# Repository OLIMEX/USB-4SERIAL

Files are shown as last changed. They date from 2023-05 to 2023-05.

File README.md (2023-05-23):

# USB-4SERIAL

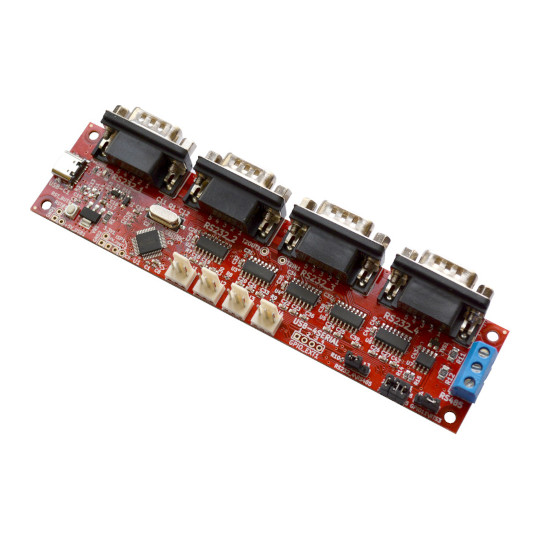
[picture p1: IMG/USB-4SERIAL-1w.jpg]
USB-4SERIAL-1w


USB-4SERIAL is Open Source Harrdware USB 2.0 High Speed to four RS232 levels or 3.3V TTL levels serial UARTs and one shared RS485 current loop serial port

## Features
* USB-C High Speed USB 2.0 connector for powering the board and communication
* The serial ports can be with baud rate up to 12Mbps on the TTL connector and up to 115200 bpx on RS232 levels connectors.
* The serial ports are compatible with 16C550 UART and support 5, 6, 7 or 8 data bits and 1 or 2 stop bits, odd, even, none, blank0, mark1 and other parity.
* Supports RTS and CTS hardware automatic flow control for the First one RS232 Serial port.
* Supports half-duplex and RS485 switching for the Fourth port.
* RS485 direction flow selectable by RTS3 or GPIO11
* Reset button
* High reliable industrial grade design -40+85C
* CE-RED and LVD certification
* Four mount holes 3 mm
* PCB dimensions: (150 x 35)mm ~ (5.9 x 1.38)"

Product page: https://www.olimex.com/Products/USB-Modules/USB-4SERIAL/open-source-hardware

## Licensee
* Hardware is released under CERN Open Hardware Licence Version 2 - Strongly Reciprocal, all silkscreen credits to Olimex should remain;
* Software is released under GPL3 Licensee
* Documentation is released under CC BY-SA 3.0

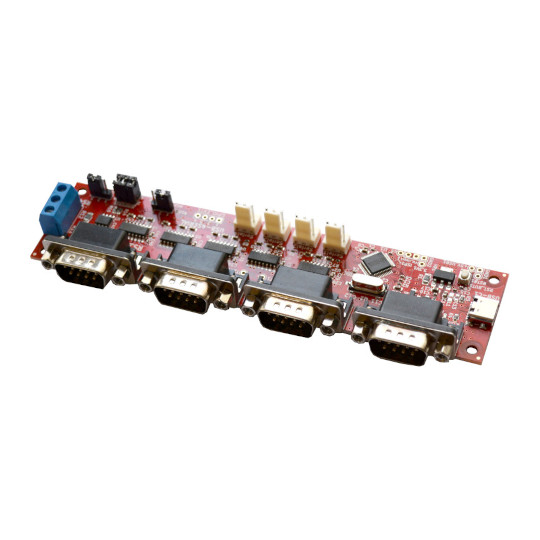
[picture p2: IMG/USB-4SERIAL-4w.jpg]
USB-4SERIAL-4w

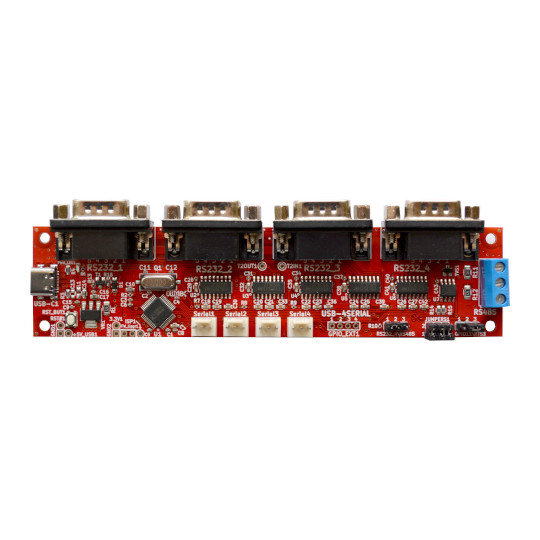
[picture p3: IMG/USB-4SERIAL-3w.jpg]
USB-4SERIAL-3w

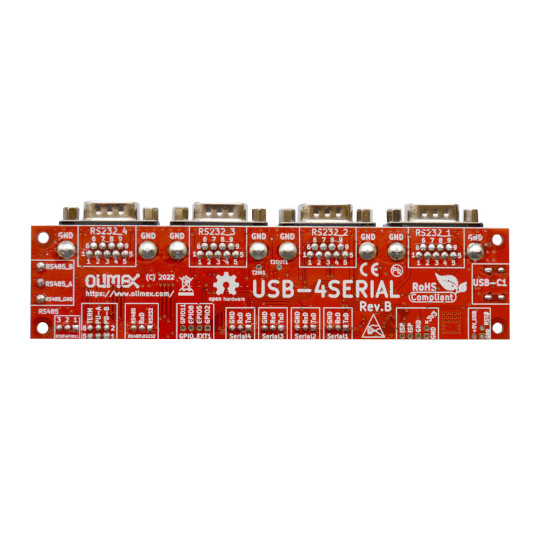
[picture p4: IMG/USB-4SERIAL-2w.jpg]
USB-4SERIAL-2w


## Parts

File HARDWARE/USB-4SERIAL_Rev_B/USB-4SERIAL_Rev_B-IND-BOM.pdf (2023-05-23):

# USB-4SERIAL_Rev_B-IND-BOM 10/04/2022

Quantity | Designation | Package | Designator
3 | 120R/R1206 | R_1206 | R1,R11,R12
5 | 330R/R0402 | R_0402 | R6,R7,R8,R9,R10
3 | 4.7k/R0603 | R_0603 | R14,R15,R16
2 | 5.1k/R0603 | R_0603 | R3,R4
2 | 12k/R0402 | R_0402 | R2,R13
1 | 20pF/50V/5%/C0G/C0603 | C_0603 | C10
2 | 39pF/50V/5%/C0G/C0402 | C_0402 | C11,C12
15 | 100nF/10V/10%/X7R/C0402 | C_0402 | C1,C2,C3,C4,C5,C6,C9, C15,C16,C28,C31,C34, C37,C40,C43
20 | 100nF/50V/20%/Y5V/C0603 | C_0603 | C18,C19,C20,C21,C22, C23,C24,C25,C26,C27, C29,C30,C32,C33,C35, C36,C38,C39,C41,C42
1 | 1uF/10V/10%/X5R/C0603 | C_0603 | C7
1 | 2.2uF/6.3V/20%/X5R/C0402 | C_0402 | C8
2 | 22uF/6.3V/20%/X5R/C0603 | C_0603 | C14,C17
1 | ESD5302F-3/TR(SOT-23-3) | SOT23-3 | TVS1
1 | 1N5819S4(SOD-123) | SOD-123 | D1
1 | LED/Red/0603 | LED_0603 | PWR_LED1
1 | LMUN2211LT1G(SOT-23) | SOT23 | T1
1 | AMS1117-3.3 (INDUSTRIAL) | SOT223 | VR1
1 | CH9344L(LQFP-48) | LQFP48 | U1
5 | ST3232BDR(SO-16) | SO-16 | U2,U3,U4,U5,U6
1 | YD3082EESA(SOIC-8_150mil) | SOIC-8_150mil | U7
1 | Q30MHz/20pF/30ppm/2P/ HC49-SM(SMD) | Q_49U3HMS | Q1
1 | YTS-A016-X | YTS-A016-X | RST_BUT1
4 | DB9_BMR(MALE) | DB9_BMR(MALE) | RS232_1,RS232_2, RS232_3,RS232_4
4 | MK-D-03-LF(WF3S) | MK-D-03-LF(WF3S)_ (CI3103P1V00) | Serial1,Serial2, Serial3,Serial4
1 | TB3-5MM (DG306-5.0-03P-12-00AH) | TB3-5mm | RS485
1 | USB-C-16P-F(A40-00119-A52-12) | USB2.0_TYPE-C (A40-00119-A52-12) | USB-C1
2 | HN1x3(1-2:Opened;2-3:Closed) | JP2 | RS232_4\RS485, GPIO11\RTS3
1 | HN2x3(Closed) | HN2x3 | JUMPERS1
1 | NA(FB0805/600R/2A) | L_0805 | L1
1 | NA(22uF/6.3V/20%/X5R/C0603) | C_0603 | C13
1 | NA(HN1x2) | HN1x2_Jumper | FW_Upgr1
1 | NA(HN1x4) | HN1x4 | GPIO_EXT1

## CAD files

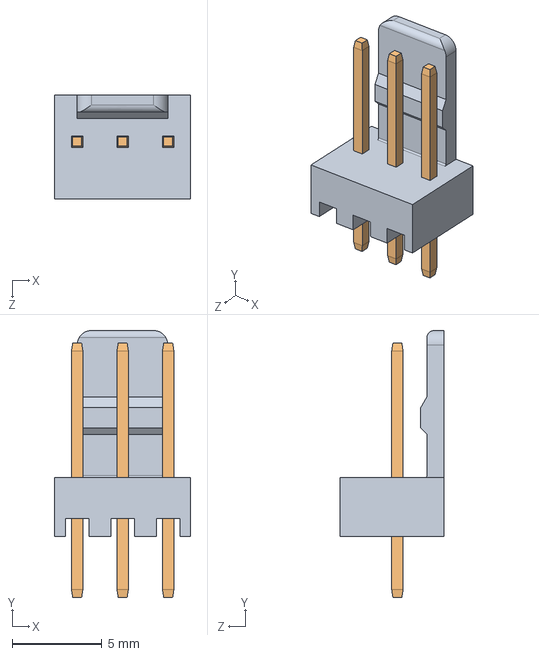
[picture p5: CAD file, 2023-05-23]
HARDWARE/USB-4SERIAL_Rev_B/3d/MK-D-03-LF(WF3S)_(CI3103P1V00_CVILUX).STEP
7.60 x 14.9 x 5.80 mm
CI31 3P
PIN V x 3

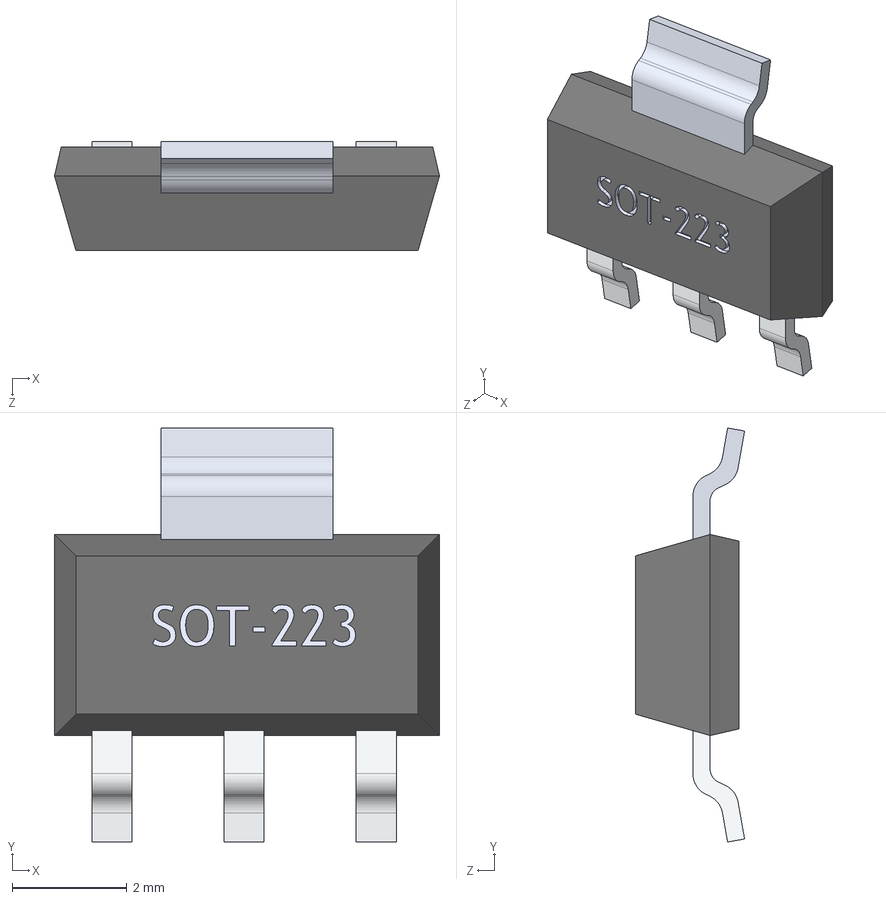
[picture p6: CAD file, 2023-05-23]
HARDWARE/USB-4SERIAL_Rev_B/3d/SOT-223-2.STEP
6.70 x 7.20 x 1.90 mm
User Library-SOT-223-2_PIN_SOT-223_2_1 x 3
User Library-SOT-223-2_SOT-223_1
User Library-SOT-223-2_PIN_SOT-223_1

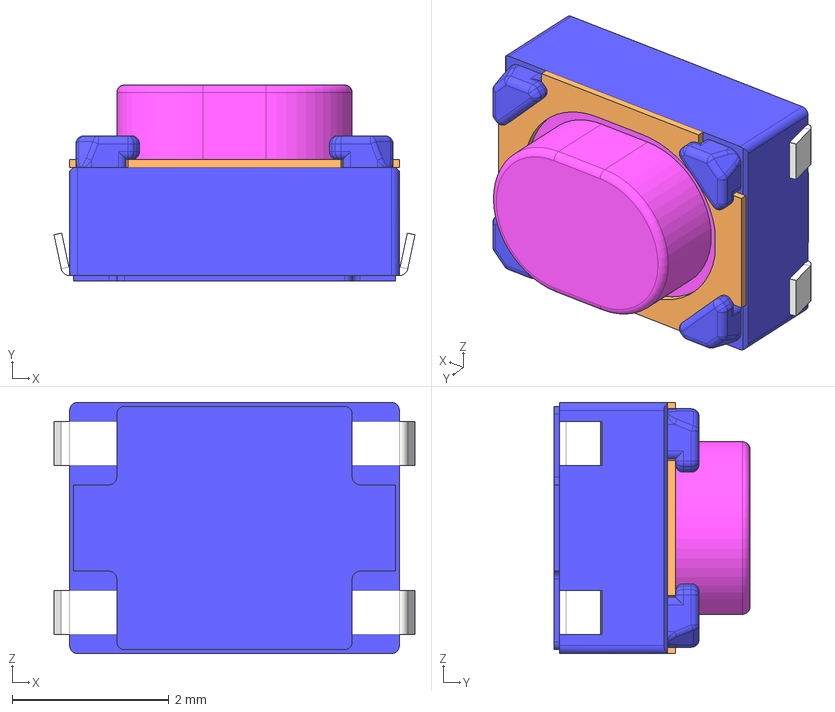
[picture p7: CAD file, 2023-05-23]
HARDWARE/USB-4SERIAL_Rev_B/3d/YTS-A016-X(SKRPABE010).stp
4.60 x 2.50 x 3.20 mm

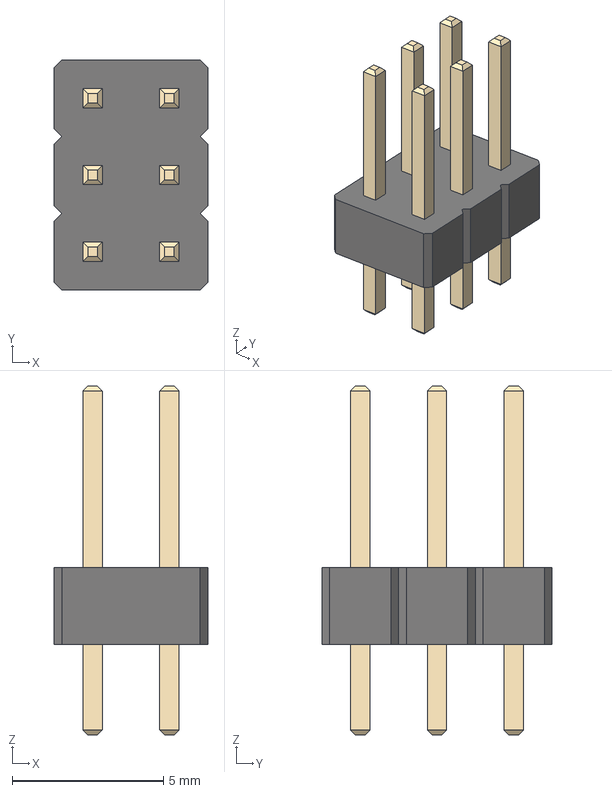
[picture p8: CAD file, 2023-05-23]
HARDWARE/USB-4SERIAL_Rev_B/3d/HN2x3(PTH)-PinHeader_2x03_P2.54mm_Vertical.step
5.08 x 7.62 x 11.5 mm

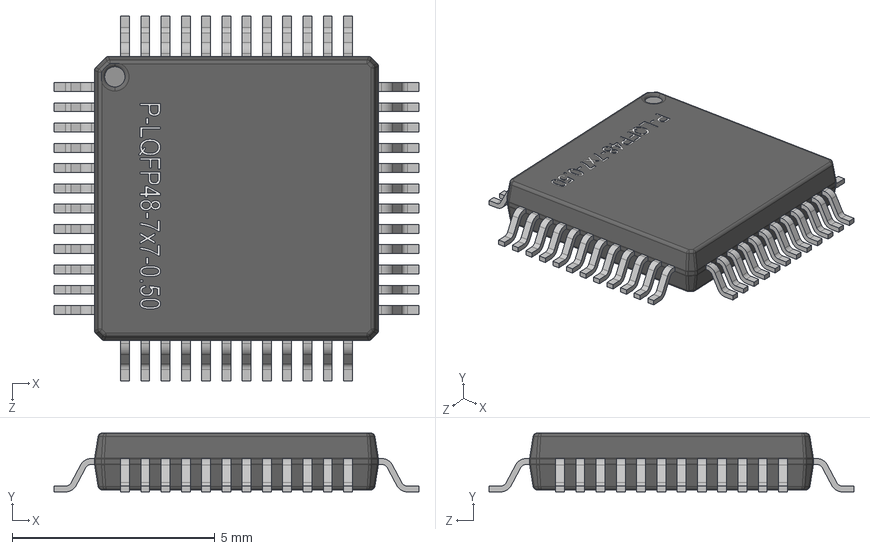
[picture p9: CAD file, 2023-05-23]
HARDWARE/USB-4SERIAL_Rev_B/3d/LQFP48-7x7-0_50.step
9.00 x 1.45 x 9.00 mm

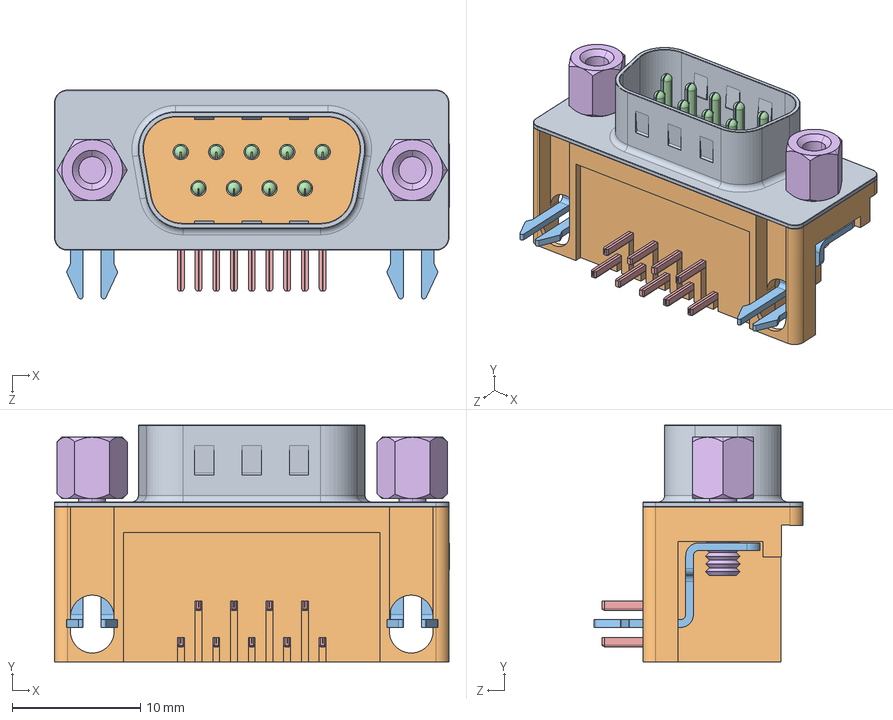
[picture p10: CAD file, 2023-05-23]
HARDWARE/USB-4SERIAL_Rev_B/3d/DB9_BMR(MALE)_CVILUX(CD6109PA1J0).STEP
30.8 x 18.5 x 16.3 mm
CDFS15P_9
cd61-塑膠架-p_9
魚叉平孔 x 2
cd51-t1 x 9
t1 x 9
螺絲 FOR J0 x 2

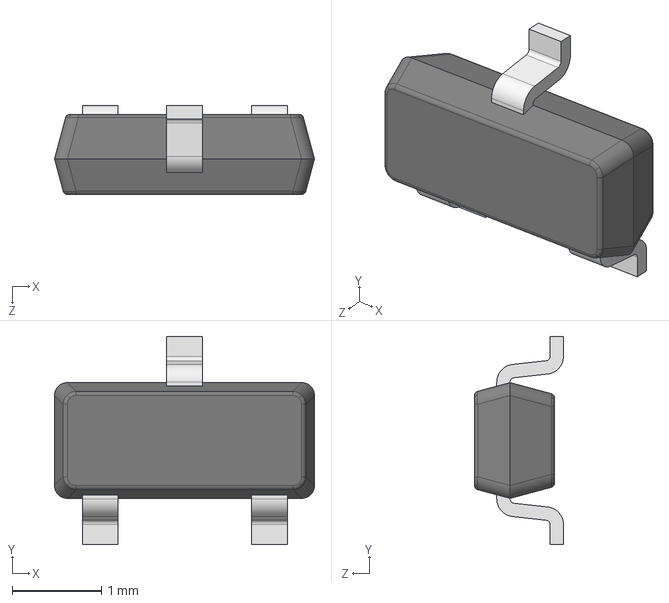
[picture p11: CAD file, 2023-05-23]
HARDWARE/USB-4SERIAL_Rev_B/3d/BAT54.step
2.92 x 2.34 x 1.00 mm

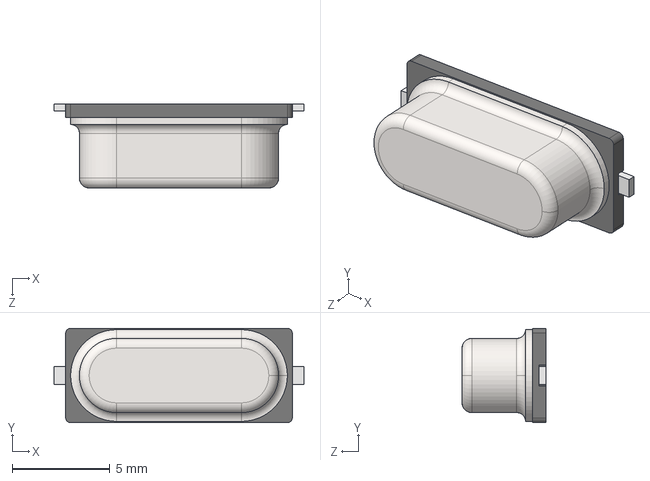
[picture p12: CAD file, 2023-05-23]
HARDWARE/USB-4SERIAL_Rev_B/3d/User_Library-Crystal_HC49_US-SM.step
12.8 x 4.83 x 4.30 mm

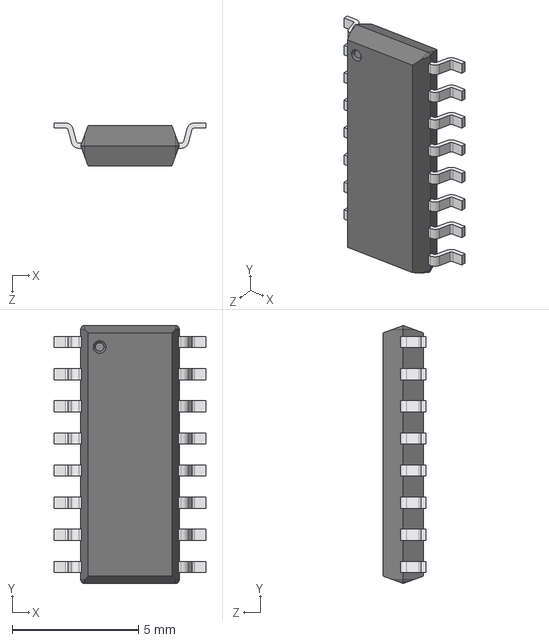
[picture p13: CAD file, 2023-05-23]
HARDWARE/USB-4SERIAL_Rev_B/3d/SO-16(SOIC-16)_Width-150mil.STEP
6.00 x 10.2 x 1.70 mm

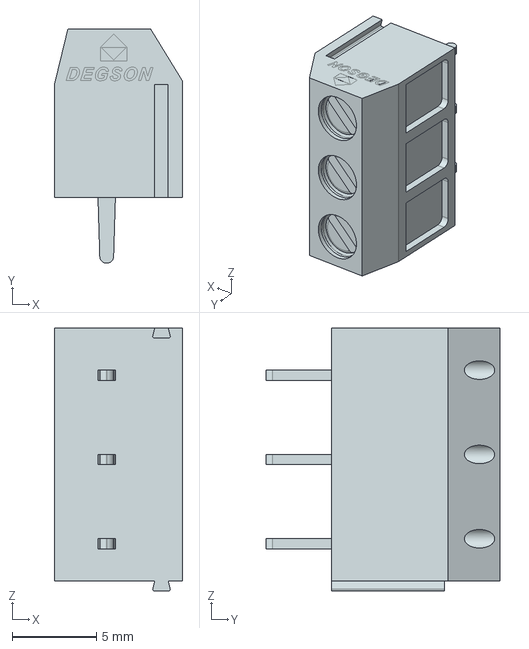
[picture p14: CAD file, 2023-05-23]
HARDWARE/USB-4SERIAL_Rev_B/3d/TB3-5MM_DG306-5.0-03P-1Y-00A(H).stp
7.60 x 13.9 x 15.6 mm

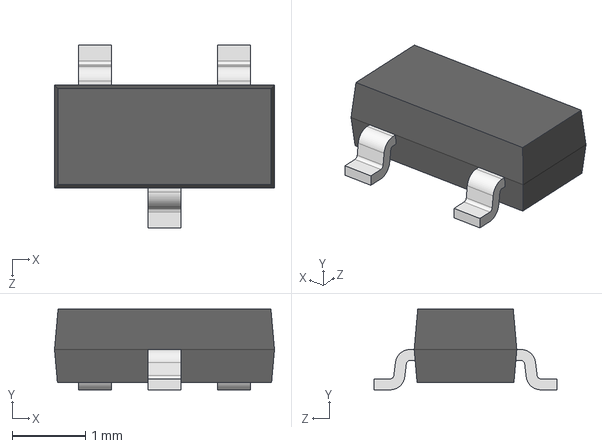
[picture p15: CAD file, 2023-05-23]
HARDWARE/USB-4SERIAL_Rev_B/3d/SOT-23.step
3.00 x 1.10 x 2.50 mm

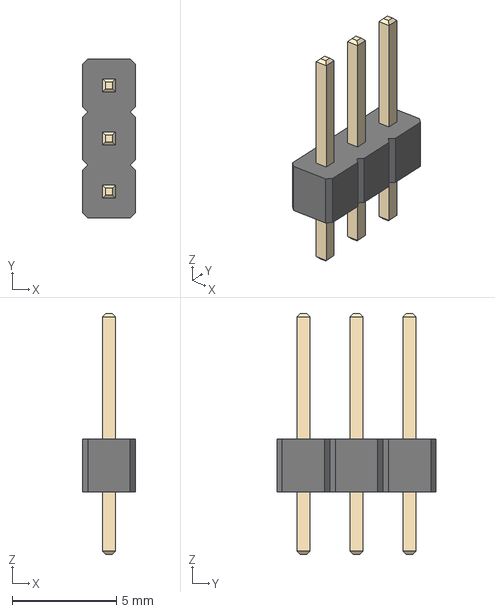
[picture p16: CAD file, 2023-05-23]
HARDWARE/USB-4SERIAL_Rev_B/3d/HN1x3-PinHeader_1x03_P2.54mm_Vertical.step
2.54 x 7.62 x 11.5 mm

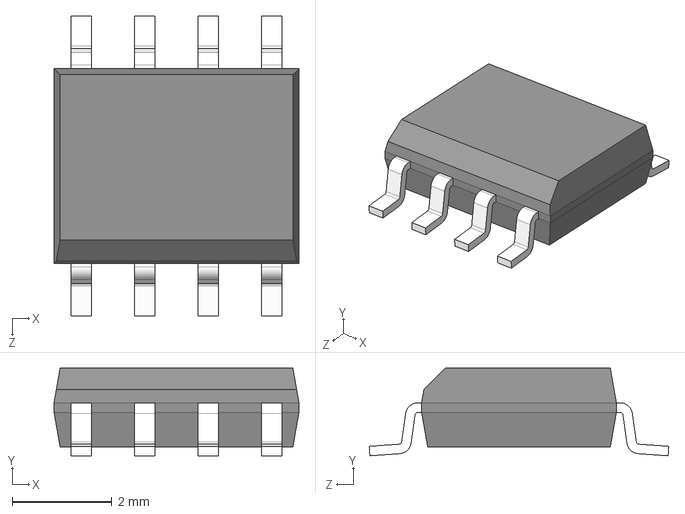
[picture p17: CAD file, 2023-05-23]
HARDWARE/USB-4SERIAL_Rev_B/3d/SO-8_150mil---SN65HVDA1050AQDRQ1.STEP
4.90 x 1.75 x 5.99 mm

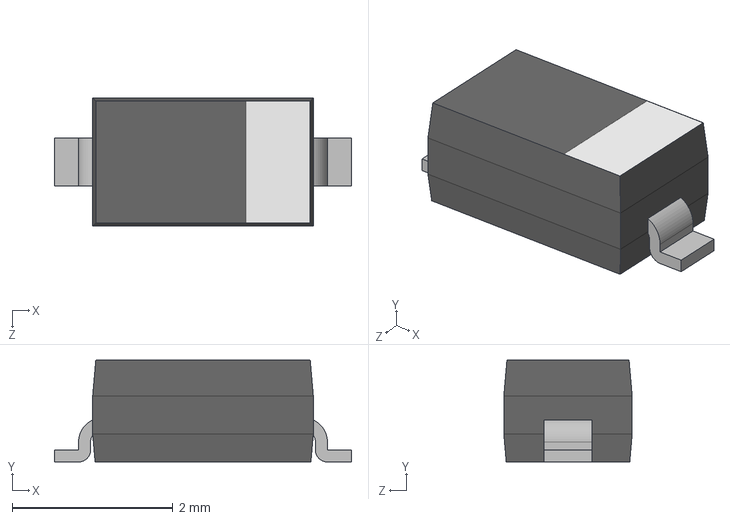
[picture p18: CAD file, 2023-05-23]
HARDWARE/USB-4SERIAL_Rev_B/3d/SOD123.step
3.70 x 1.27 x 1.60 mm

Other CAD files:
HARDWARE/USB-4SERIAL_Rev_B/3d/70054376.stp

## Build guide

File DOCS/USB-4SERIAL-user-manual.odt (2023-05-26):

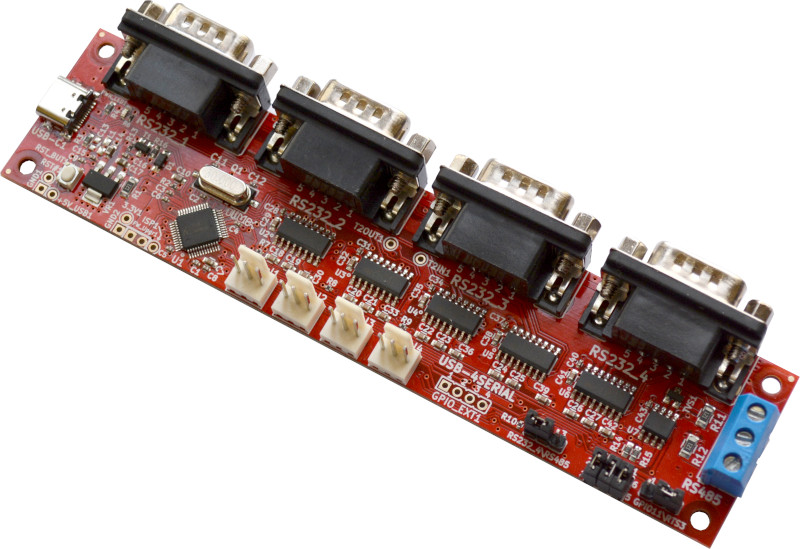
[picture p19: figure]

USB-4SERIAL

User Manual

Rev.1.0 May 2023 olimex.com

# Introduction to USB-4SERIAL

USB-4SERIAL (https://www.olimex.com/Products/USB-Modules/USB-4SERIAL/open-source-hardware) is Open Source Hardware Industrial grade board which adds Four Serial ports to any computer with USB port.

The First one of these Four Serial ports have RTS / CTS control while the other three are only with Tx and Rx signals.

The Fourth Serial port can be configured to have RS232 levels or RS485 current loop, thus enabling communication with industrial RS485 equipment.

The Serial ports have DB9 connectors with RS232 levels, but TTL 3.3V level Serial ports are also available on separate 0.1” 2.54mm step connectors which you can connect to embedded boards working on 3.3V

If you have more than one USB ports you can connect more USB-4SERIAL (https://www.olimex.com/Products/USB-Modules/USB-4SERIAL/open-source-hardware) to each of them and you can have multiply x 4 Serial ports.

## USB-4SERIAL features

- USB-C High Speed USB 2.0 connector for powering the board and communication
- The serial ports can be with baud rate up to 12Mbps on the TTL connector and up to 115200 bpx on RS232 levels connectors.
- The serial ports are compatible with 16C550 UART and support 5, 6, 7 or 8 data bits and 1 or 2 stop bits, odd, even, none, blank0, mark1 and other parity.
- Supports RTS and CTS hardware automatic flow control for the First one RS232 Serial port.
- Supports half-duplex and RS485 switching for the Fourth port.
- RS485 direction flow selectable by RTS3 or GPIO11
- Reset button
- High reliable industrial grade design -40+85C
- CE-RED and LVD certification
- Four mount holes 3 mm
- PCB dimensions: (150 x 35)mm ~ (5.9 x 1.38)"

## Order codes for USB-4SERIAL and accessories:

USB-4SERIAL (https://www.olimex.com/Products/USB-Modules/USB-4SERIAL/open-source-hardware) industrial grade -40+85C board

CABLE-USB-A-C-1M (https://www.olimex.com/Products/Components/Cables/CABLE-USB-A-C-1M/) USB-A to USB-C cable 1 meter long

# HARDWARE

## USB-4SERIAL layout:

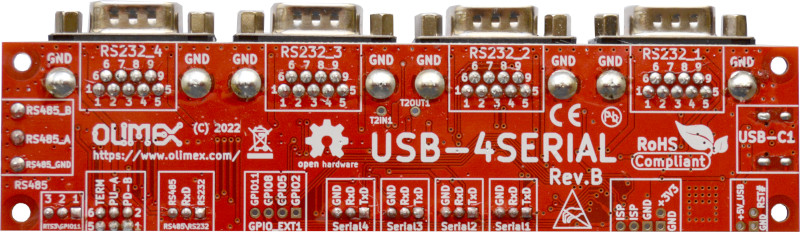
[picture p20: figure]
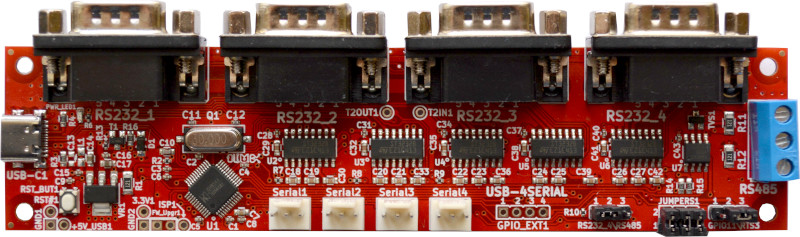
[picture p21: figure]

RS232 Serial1

RS232 Serial2

RS232 Serial3

RS232 Serial4

RS485

USB-C

TTL Serial1

TTL Serial2

TTL Serial3

TTL Serial4

RS232/RS485

Select Jumper

RS485 config

Jumper

RTS3/GPIO

Jumper

## USB-4SERIAL schematic:

USB-4SERIAL (https://www.olimex.com/Products/USB-Modules/USB-4SERIAL/open-source-hardware) is Open Source Hardware designed with KiCAD, the source files are on GitHub (https://github.com/OLIMEX/USB-4SERIAL) and the Latest schematic in PDF format is here (https://github.com/OLIMEX/USB-4SERIAL/blob/main/HARDWARE/USB-4SERIAL_Rev_B/USB-4SERIAL_Rev_B.pdf).

## USB-4SERIAL jumpers

RS232/RS485 Jumper

1-2 selects RS232 function for Serial4

2-3 selects RS485 function for Serial4

RS485 Jumper

1-2 Pull down resistor to RS485 B node

3-4 Pull up resistor to RS485 A node

5-6 Terminal Resistor between A-B

RTS3/GPIO Jumper

1-2 selects RS485 data flow to be controlled by GPIO11

2-3 selects RS485 data flow to be controlled by RTS3

# SOFTWARE:

Linux drivers:

You need to download and install the drivers from GitHub.

When USB-C is plug Four new serial ports will be visible in /dev/tty*

Windows drivers:

Usually are not necessary, When USB-C is plug Four COM ports will be visible in the Windows Device Manager

# Revision History

Revision 1.0 May 2023

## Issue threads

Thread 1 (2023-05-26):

Small typo in manual

romainreignier, 2023-05-26:
Hi, nice product!

While browsing the manual, I have noticed a small typo on page 9.
In the center of the page, a `p` is missing in "RS485 Jumer".

It's nice to provide the ODT file for the manual, I could have opened a pull request, but you would not have been able to easily see the diff of my changes.
You might want to switch to the `.fodt` file format, which is a flat XML version of the ODT. The file is bigger because it's ASCII but it allows to review the changes in git.

Closed 2023-05-26.

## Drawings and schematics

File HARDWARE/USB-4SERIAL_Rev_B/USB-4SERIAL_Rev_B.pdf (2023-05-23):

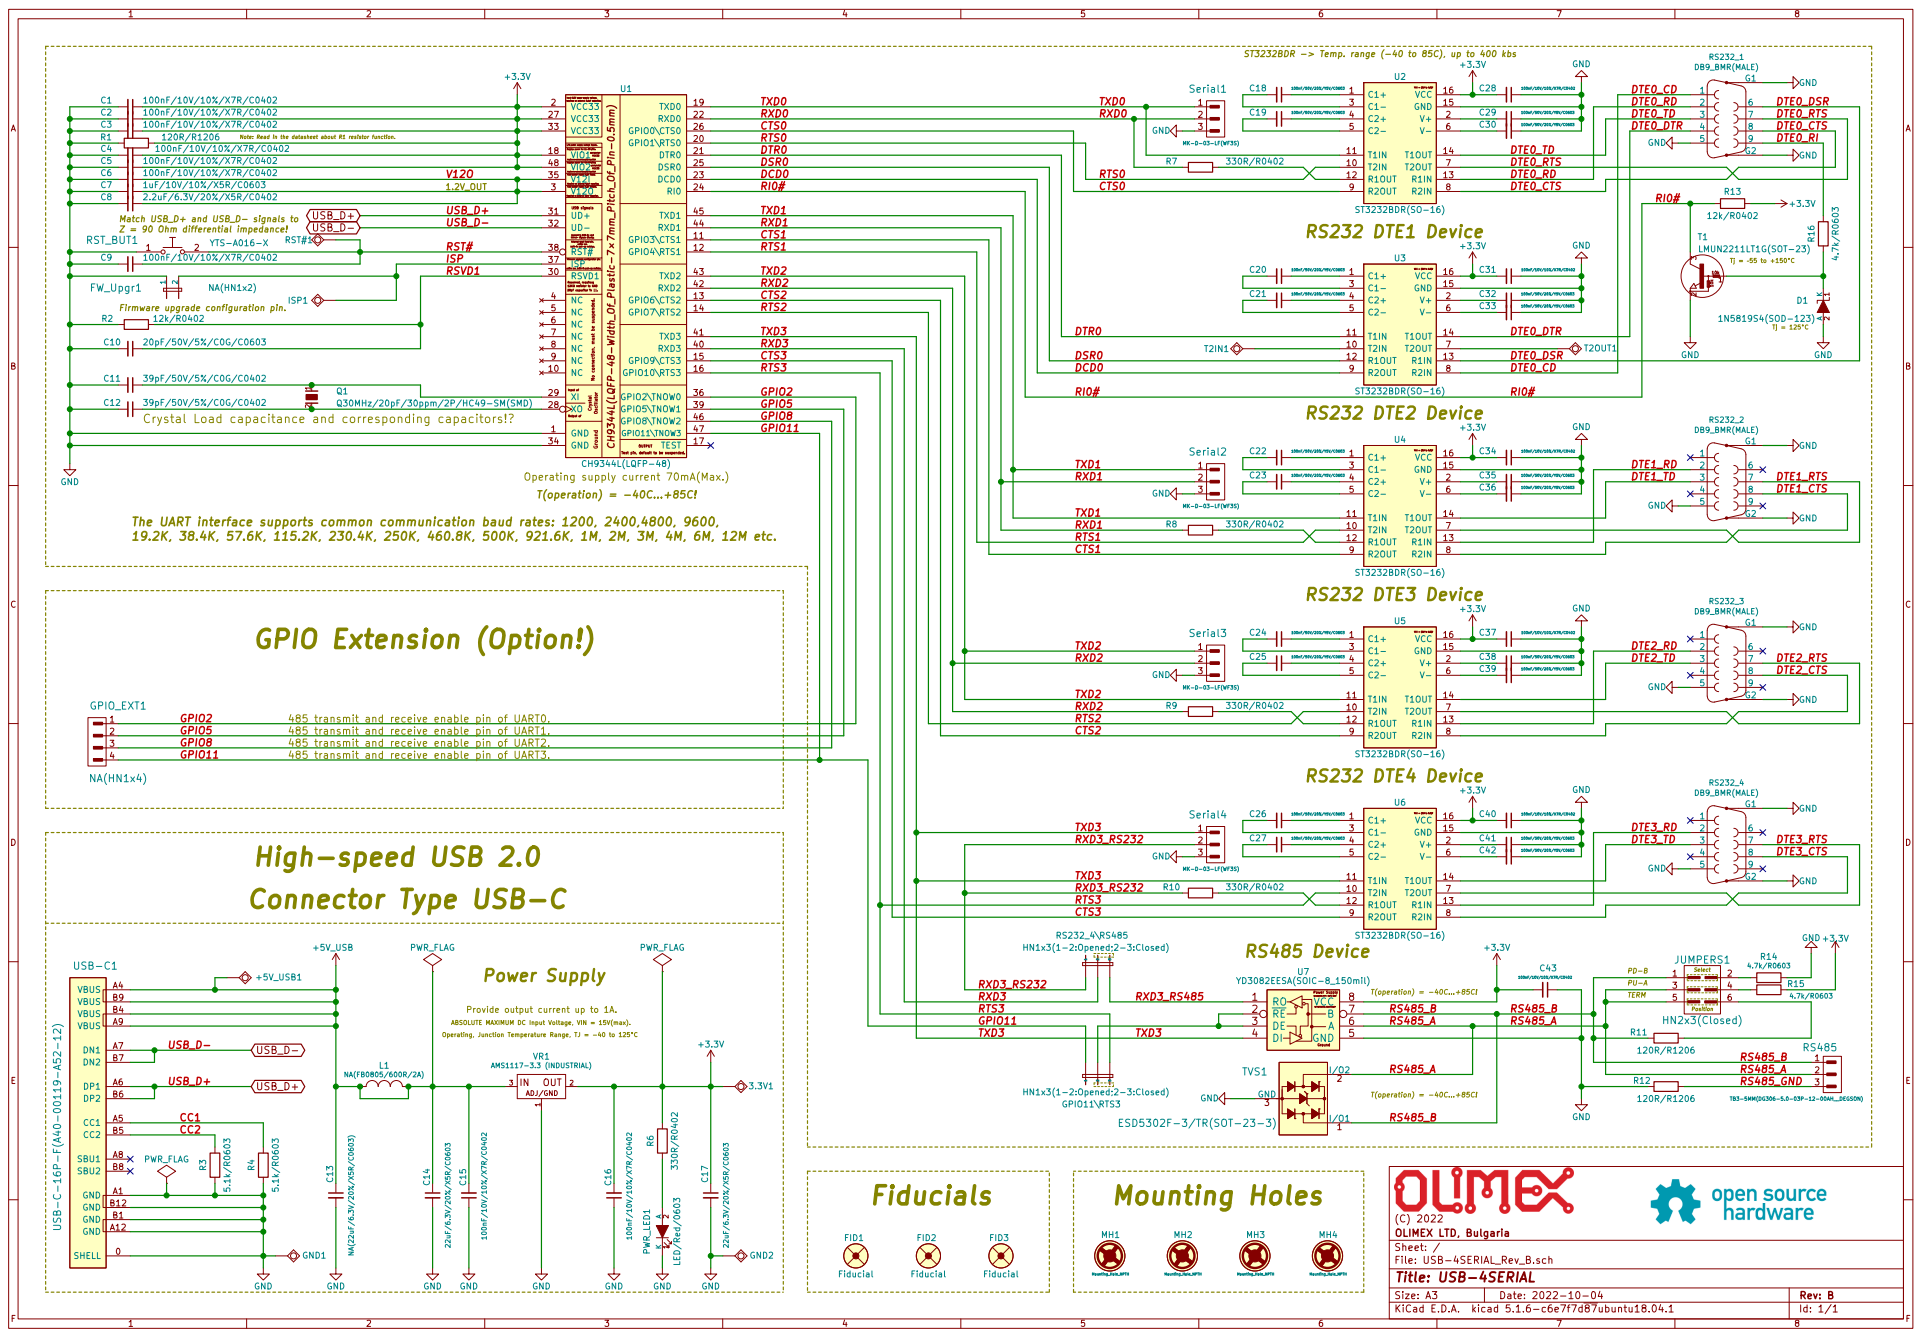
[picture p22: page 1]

requires an external 0.1uF capacitor. Requires an external 3.3uF capacitor. Requires an external decoupling capacitor! Requires an external decoupling capacitor! Reserved, requires:

ST3232BDR -> Temp. range (-40 to 85C), up to 400 kbs

Input 3.3V power supply voltage,

Note: Read in the datasheet about R1 resistor function.

I/O power supply voltage inputs.
Supplys power for 11-26 pins. Supplys power for 42-48 pins.
1.8V/2.5V/3.3V 12K resistor to GND
20pF capacitor in ||. active low, active low, built-in pull-up resistor. built-in pull-up resistor. Connect to USB D+ and Core power supply 1.2V input. Core power supply 1.2V output. External reset input pin, Firmware upgrade configuration pin,

Requires an external 0.1uF capacitor.

Match USB_D+ and USB_D- signals to Z = 90 Ohm differential impedance!

USB D- Signals directly. USB signals

Test pin, default to be suspended.

485 transmit and receive enable pin of UART3. GPIO Extension (Option!)

ABSOLUTE MAXIMUM DC Input Voltage, VIN = 15V(max). Operating, Junction Temperature Range, TJ = -40 to 125°C 485 transmit and receive enable pin of UART0. 485 transmit and receive enable pin of UART1. 485 transmit and receive enable pin of UART2. Power Supply

T(operation) = -40C...+85C! High-speed USB 2.0
Connector Type USB-C

Provide output current up to 1A.

File: USB-4SERIAL_Rev_B.sch Sheet: / OLIMEX LTD, Bulgaria

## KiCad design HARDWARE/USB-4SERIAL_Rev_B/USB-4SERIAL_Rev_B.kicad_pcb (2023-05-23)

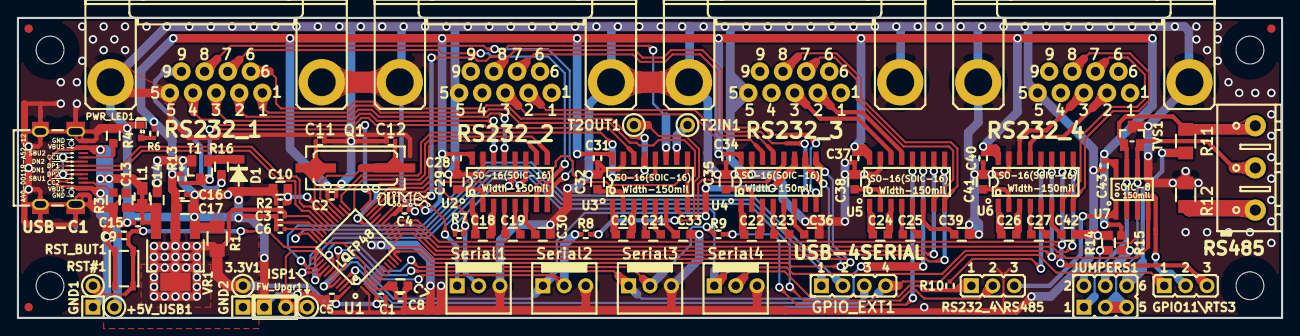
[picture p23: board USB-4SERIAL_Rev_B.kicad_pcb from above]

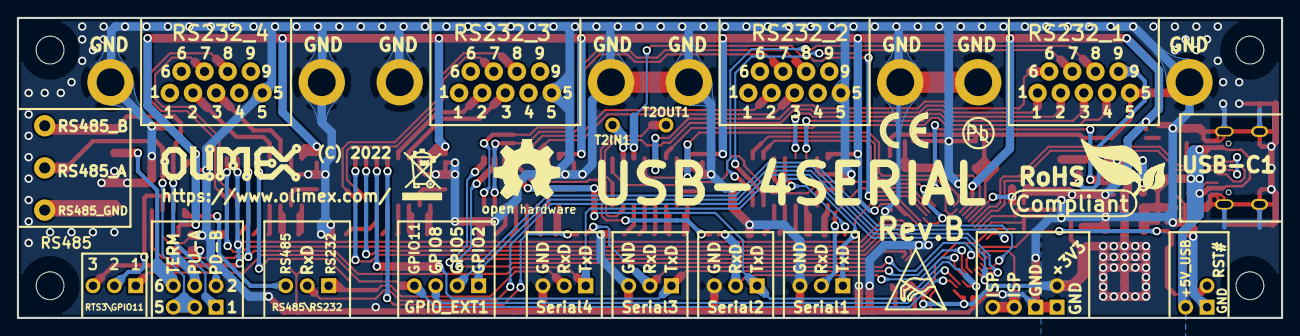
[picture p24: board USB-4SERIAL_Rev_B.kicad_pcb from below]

Board: 2 copper layers, 149.9 x 35.6 mm, 111 parts (7 on the bottom side), 104 nets.

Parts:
3.3V1: TESTPAD; TP_PTH-CIRCLE
+5V_USB1: TESTPAD; TP_PTH-CIRCLE
C1, C2, C3, C4, C5, C6, C9, C15, C16, C28, C31, C34, C37, C40, C43: 100nF/10V/10%/X7R/C0402; C_0402_5MIL_DWS
C7: 1uF/10V/10%/X5R/C0603; C_0603_5MIL_DWS
C8: 2.2uF/6.3V/20%/X5R/C0402; C_0402_5MIL_DWS
C10: 20pF/50V/5%/C0G/C0603; C_0603_5MIL_DWS
C11, C12: 39pF/50V/5%/C0G/C0402; C_0402_5MIL_DWS
C13: NA(22uF/6.3V/20%/X5R/C0603); C_0603_5MIL_DWS
C14, C17: 22uF/6.3V/20%/X5R/C0603; C_0603_5MIL_DWS
C18, C19, C20, C21, C22, C23, C24, C25, C26, C27, C29, C30, C32, C33, C35, C36, C38, C39, C41, C42: 100nF/50V/20%/Y5V/C0603; C_0603_5MIL_DWS
D1: 1N5819S4(SOD-123); SOD-123_1C-2A_KA
FID1, FID2, FID3: Fiducial; Fiducial1x3
FW_Upgr1: NA(HN1x2); HN1x2_Jumper
GND1, GND2: TESTPAD; TP_PTH-SQUARE
GPIO11\RTS3: HN1x3(1-2:Opened;2-3:Closed); JP2
GPIO_EXT1: NA(HN1x4); HN1x4
ISP1: TESTPAD; TP_PTH-CIRCLE
JUMPERS1: HN2x3(Closed); HN2x3
L1: NA(FB0805/600R/2A); L_0805_5MIL_DWS
Logo_OLIMEX_SMALL_TB: Logo_OLIMEX_SMALL_TB
Logo_OLIMEX_TB: Logo_OLIMEX_TB
MH1, MH2, MH3, MH4: Mounting_Hole_NPTH; Mounting_Hole_Drill-3.3mm_Clerance-7mm
PWR_LED1: LED/Red/0603; LED_0603_KA
Q1: Q30MHz/20pF/30ppm/2P/HC49-SM(SMD); Q_49U3HMS
R1, R11, R12: 120R/R1206; R_1206_5MIL_DWS
R2, R13: 12k/R0402; R_0402_5MIL_DWS
R3, R4: 5.1k/R0603; R_0603_5MIL_DWS
R6, R7, R8, R9, R10: 330R/R0402; R_0402_5MIL_DWS
R14, R15, R16: 4.7k/R0603; R_0603_5MIL_DWS
RS232_1, RS232_2, RS232_3, RS232_4: DB9_BMR(MALE)
RS232_4\RS485: HN1x3(1-2:Opened;2-3:Closed); JP2
RS485: TB3-5MM(DG306-5.0-03P-12-00AH__DEGSON); TB3-5mm
RST#1: TESTPAD; TP_PTH-CIRCLE
RST_BUT1: YTS-A016-X
Serial1, Serial2, Serial3, Serial4: MK-D-03-LF(WF3S); MK-D-03-LF(WF3S)_(CI3103P1V00_CVILUX)
Sign_Antistatic: Sign_Antistatic
Sign_CE: CE_Sign
Sign_OSHW_8x8: Sign_OSHW_8x8
Sign_PB-Free: Sign_PB-Free
Sign_RecycleBin_1: Sign_RecycleBin_1
Sign_RoHS_1: Sign_RoHS_1
T1: LMUN2211LT1G(SOT-23); SOT23
T2IN1, T2OUT1: TESTPAD; TP_PTH-CIRCLE
TVS1: ESD5302F-3/TR(SOT-23-3); SOT23-3
U1: CH9344L(LQFP-48); LQFP48
U2, U3, U4, U5, U6: ST3232BDR(SO-16); SO-16
U7: YD3082EESA(SOIC-8_150mil); SOIC-8_150mil
USB-C1: USB-C-16P-F(A40-00119-A52-12); USB2.0_TYPE-C(A40-00119-A52-12)
VR1: AMS1117-3.3 (INDUSTRIAL); SOT223

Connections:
+3V3: 3.3V1.1, C1.1, C2.1, C3.1, C4.1, C5.1, C16.2, C17.1, C28.2, C31.2, C34.2, C37.2, C40.2, C43.2, R1.2, R6.1, R13.2, R15.1, U1.2, U1.18, U1.27, U1.33, U1.48, U2.16, U3.16, U4.16, U5.16, U6.16, U7.8, VR1.2
+5V_USB: +5V_USB1.1, C13.1, C14.1, C15.2, L1.1, L1.2, USB-C1.A4, USB-C1.A9, USB-C1.B4, USB-C1.B9, VR1.3
/CC1: R4.2, USB-C1.A5
/CC2: R3.2, USB-C1.B5
/CTS0: U1.26, U2.9
/CTS1: U1.11, U4.9
/CTS2: U1.13, U5.9
/CTS3: U1.15, U6.9
/DCD0: U1.23, U3.9
/DSR0: U1.25, U3.12
/DTE0_CD: RS232_1.1, U3.8
/DTE0_CTS: RS232_1.8, U2.8
/DTE0_DSR: RS232_1.6, U3.13
/DTE0_DTR: RS232_1.4, U3.14
/DTE0_RD: RS232_1.2, U2.13
/DTE0_RI: R16.1, RS232_1.9
/DTE0_RTS: RS232_1.7, U2.7
/DTE0_TD: RS232_1.3, U2.14
/DTE1_CTS: RS232_2.8, U4.8
/DTE1_RD: RS232_2.2, U4.13
/DTE1_RTS: RS232_2.7, U4.7
/DTE1_TD: RS232_2.3, U4.14
/DTE2_CTS: RS232_3.8, U5.8
/DTE2_RD: RS232_3.2, U5.13
/DTE2_RTS: RS232_3.7, U5.7
/DTE2_TD: RS232_3.3, U5.14
/DTE3_CTS: RS232_4.8, U6.8
/DTE3_RD: RS232_4.2, U6.13
/DTE3_RTS: RS232_4.7, U6.7
/DTE3_TD: RS232_4.3, U6.14
/DTR0: U1.21, U3.11
/GPIO2: GPIO_EXT1.1, U1.36
/GPIO5: GPIO_EXT1.2, U1.39
/GPIO8: GPIO_EXT1.3, U1.46
/GPIO11: GPIO11\RTS3.1, GPIO_EXT1.4, U1.47
/ISP: FW_Upgr1.2, ISP1.1, U1.37
/RI0#: R13.1, T1.3, U1.24
/RS485_A: JUMPERS1.3, JUMPERS1.5, RS485.2, TVS1.2, U7.6
/RS485_B: JUMPERS1.1, R11.2, RS485.1, TVS1.1, U7.7
/RS485_GND: R12.2, RS485.3
/RST#: C9.1, RST#1.1, RST_BUT1.2, U1.38
/RSVD1: C10.1, R2.2, U1.30
/RTS0: U1.20, U2.10
/RTS1: U1.12, U4.10
/RTS2: U1.14, U5.10
/RTS3: GPIO11\RTS3.3, U1.16, U6.10
/RXD0: R7.1, Serial1.2, U1.22
/RXD1: R8.1, Serial2.2, U1.44
/RXD2: R9.1, Serial3.2, U1.42
/RXD3: RS232_4\RS485.2, U1.40
/RXD3_RS232: R10.1, RS232_4\RS485.1, Serial4.2
/RXD3_RS485: RS232_4\RS485.3, U7.1
/TXD0: Serial1.1, U1.19, U2.11
/TXD1: Serial2.1, U1.45, U4.11
/TXD2: Serial3.1, U1.43, U5.11
/TXD3: Serial4.1, U1.41, U6.11, U7.4
/V12O: C6.1, C7.1, C8.1, U1.3, U1.35
GND: C1.2, C2.2, C3.2, C4.2, C5.2, C6.2, C7.2, C8.2, C9.2, C10.2, C11.2, C12.2, C13.2, C14.2, C15.1, C16.1, C17.2, C28.1, C29.1, C30.1, C31.1, C32.1, C33.1, C34.1, C35.1, C36.1, C37.1, C38.1, C39.1, C40.1, C41.1, C42.1, C43.1, D1.2, FW_Upgr1.1, GND1.1, GND2.1, PWR_LED1.1, R1.1, R2.1, R3.1, R4.1, R12.1, R14.1, RS232_1.5, RS232_1.G1, RS232_1.G2, RS232_2.5, RS232_2.G1, RS232_2.G2, RS232_3.5, RS232_3.G1, RS232_3.G2, RS232_4.5, RS232_4.G1, RS232_4.G2, RST_BUT1.1, Serial1.3, Serial2.3, Serial3.3, Serial4.3, T1.2, TVS1.3, U1.1, U1.34, U2.15, U3.15, U4.15, U5.15, U6.15, U7.5, USB-C1.0, USB-C1.A1, USB-C1.A12, USB-C1.B1, USB-C1.B12, VR1.1
unnamed: C11.1, Q1.1, U1.29
unnamed: C12.1, Q1.2, U1.28
unnamed: C18.1, U2.1
unnamed: C18.2, U2.3
unnamed: C19.1, U2.4
unnamed: C19.2, U2.5
unnamed: C20.1, U3.1
unnamed: C20.2, U3.3
unnamed: C21.1, U3.4
unnamed: C21.2, U3.5
unnamed: C22.1, U4.1
unnamed: C22.2, U4.3
unnamed: C23.1, U4.4
unnamed: C23.2, U4.5
unnamed: C24.1, U5.1
unnamed: C24.2, U5.3
unnamed: C25.1, U5.4
unnamed: C25.2, U5.5
unnamed: C26.1, U6.1
unnamed: C26.2, U6.3
unnamed: C27.1, U6.4
unnamed: C27.2, U6.5
unnamed: C29.2, U2.2
unnamed: C30.2, U2.6
unnamed: C32.2, U3.2
unnamed: C33.2, U3.6
unnamed: C35.2, U4.2
unnamed: C36.2, U4.6
unnamed: C38.2, U5.2
unnamed: C39.2, U5.6
unnamed: C41.2, U6.2
unnamed: C42.2, U6.6
unnamed: D1.1, R16.2, T1.1
unnamed: GPIO11\RTS3.2, U7.2, U7.3
unnamed: JUMPERS1.2, R14.2
unnamed: JUMPERS1.4, R15.2
unnamed: JUMPERS1.6, R11.1
unnamed: PWR_LED1.2, R6.2
unnamed: R7.2, U2.12
unnamed: R8.2, U4.12
unnamed: R9.2, U5.12
unnamed: R10.2, U6.12
unnamed: T2IN1.1, U3.10
unnamed: T2OUT1.1, U3.7
USB_D+: U1.31, USB-C1.A6, USB-C1.B6
USB_D-: U1.32, USB-C1.A7, USB-C1.B7

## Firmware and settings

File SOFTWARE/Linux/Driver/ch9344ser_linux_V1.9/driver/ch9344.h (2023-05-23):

#ifndef _CH9344_H
#define _CH9344_H

/*
 * Baud rate and default timeout
 */
#define DEFAULT_BAUD_RATE 9600
#define DEFAULT_TIMEOUT   2000
#define DEFAULT_CLOSETIMEOUT 100 

/*
 * CMSPAR, some architectures can't have space and mark parity.
 */

#ifndef CMSPAR
#define CMSPAR			0
#endif

/*
 * Major and minor numbers.
 */

#define CH9344_TTY_MAJOR		168
#define CH9344_TTY_MINORS		256


#define CH9344_CTO_D		0x01
#define CH9344_CTO_R		0x02
#define CH9344_CTI_C		0x01
#define CH9344_CTI_DS		0x02
#define CH9344_CTI_R		0x04
#define CH9344_CTI_DC		0x08

#define CH9344_LO			0x10
#define CH9344_LP			0x20
#define CH9344_LF			0x40
#define CH9344_LB			0x80

#define CMD_W_R				0xC0
#define CMD_W_BR			0x80
#define CMD_S_T		   		0x20

#define CMD_WB_E			0x90
#define CMD_RB_E 			0xC0

#define M_NOR   			0x00
#define M_RS    			0x01
#define M_IO    			0x02
#define M_HF 				0x03

#define G_DO 				0x01
#define G_DI	  			0x00

#define R_MOD 				0x97
#define R_IO_D  			0x98
#define R_IO_O  			0x99
#define R_IO_I   			0x9b
#define R_TM_O				0x9c
#define R_INIT				0xa1

#define R_IO_CE				0xa3
#define R_IO_CD				0xa4
#define R_IO_CO				0xa5
#define R_IO_CI				0xa7
#define R_IO_RE				0xaa
#define R_IO_RD				0xab

#define R_C1 				0x01
#define R_C2 				0x02
#define R_C3 				0x03
#define R_C4 				0x04
#define R_C5 				0x06

#define R_II_B1 			0x06
#define R_II_B2 			0x02
#define R_II_B3				0x00

/*
 * Internal driver structures.
 */

#define CH9344_NW  4
#define CH9344_NR  32

#define NUMSTEP 8
#define MAXGPIO 48
#define MAXPORT 8

#define IO_H 1
#define IO_L 0

struct ch9344_wb {
	unsigned char *buf;
	dma_addr_t dmah;
	int len;
	int use;
	struct urb		*urb;
	struct ch9344		*instance;
	int portnum;
};

struct ch9344_rb {
	int			size;
	unsigned char		*base;
	dma_addr_t		dma;
	int			index;
	struct ch9344		*instance;
};

struct usb_ch9344_line_coding {
	__le32	dwDTERate;
	__u8	bCharFormat;
#define SB1			0
#define SB1_5			1
#define SB2			2

	__u8	bParityType;
#define PAN			0
#define PAO			1
#define PAE			2
#define PAM			3
#define PAS			4

	__u8	bDataBits;
} __attribute__((packed));

struct ch9344_ttyport {
	struct tty_port port;
	int portnum;
	void *portdata;
	bool write_empty;
	struct usb_ch9344_line_coding line;		/* bits, stop, parity */
	unsigned int ctrlin;				/* input control lines (DCD, DSR, RI, break, overruns) */
	unsigned int ctrlout;				/* output control lines (DTR, RTS) */
	struct async_icount iocount;			/* counters for control line changes */
	struct async_icount oldcount;			/* for comparison of counter */
	u8 uartmode;					/* uart mode */
	unsigned char clocal;				/* termios CLOCAL */
	wait_queue_head_t wioctl;			/* for write */
	wait_queue_head_t wmodemioctl;			/* for ioctl */
	bool isopen;
	struct work_struct work;			/* work queue entry for line discipline waking up */
};

typedef enum {
	CHIP_CH9344 = 0,
	CHIP_CH348L = 1,
	CHIP_CH348Q = 2,
} CHIPTYPE;

struct ch9344 {
	struct usb_device *dev;				/* the corresponding usb device */
	struct usb_interface *control;			/* control interface */
	struct usb_interface *data;			/* data interface */
	unsigned int num_ports;
	bool modeline9;
	struct ch9344_ttyport ttyport[MAXPORT];		/* our tty port data */
	CHIPTYPE chiptype;
	int port_offset;

	struct urb *cmdreadurb;				/* urbs */
	u8 *cmdread_buffer;				/* buffers of urbs */
	dma_addr_t cmdread_dma;				/* dma handles of buffers */

	int opencounts;
	struct ch9344_wb wb[MAXPORT][CH9344_NW];
	unsigned long read_urbs_free;
	struct urb *read_urbs[CH9344_NR];
	struct ch9344_rb read_buffers[CH9344_NR];
	struct ch9344_wb *putbuffer;			/* for ch9344_tty_put_char() */
	int rx_buflimit;
	int rx_endpoint;
	int tx_endpoint;
	int cmdtx_endpoint;
	int cmdrx_endpoint;
	int ctrl_endpoint;

	spinlock_t read_lock;
	int write_used;					/* number of non-empty write buffers */
	int transmitting;
	spinlock_t write_lock;
	struct mutex mutex;
	bool disconnected;
	u64 gpioenables;
	u64 gpiodirs;
	u64 gpiovals;
	u64 gpiovalins;
	u8 gpiodir[MAXGPIO];				/* gpio direction */
	u8 gpioval[MAXGPIO];				/* gpio output value */
	u16 gpiovalin;					/* gpio input value */
	bool gpio_recv;					/* gpio input sync flag */
	wait_queue_head_t wgpioioctl;			/* for gpio input ioctl */
	struct mutex gpiomutex;
	unsigned int writesize;				/* max packet size for the output bulk endpoint */
	unsigned int readsize, cmdsize;			/* buffer sizes for freeing */
	unsigned int ctrlsize;
	unsigned int minor;				/* ch9344 minor number */
	unsigned int susp_count;			/* number of suspended interfaces */
	u8 bInterval;
	struct usb_anchor delayed;			/* writes queued for a device about to be woken */
	unsigned long quirks;
};


/* constants describing various quirks and errors */
#define SINGLE_RX_URB			BIT(1)
#define NO_DATA_INTERFACE		BIT(4)
#define IGNORE_DEVICE			BIT(5)
#define QUIRK_CONTROL_LINE_STATE	BIT(6)
#define CLEAR_HALT_CONDITIONS		BIT(7)

#endif

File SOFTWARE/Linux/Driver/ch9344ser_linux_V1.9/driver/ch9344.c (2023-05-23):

/*
 * USB serial driver for USB to Quad UARTs chip ch9344 and USB to Octal UARTs chip ch348.
 *
 * Copyright (C) 2021 Nanjing Qinheng Microelectronics Co., Ltd.
 * Web: http://wch.cn
 * Author: WCH@TECH39 <tech@wch.cn>
 *
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
 * System required:
 * Kernel version beyond 3.4.x
 * Update Log:
 * V1.0 - initial version
 * V1.1 - added supports for high baudrates 2M, 4M and 6M
 * V1.2 - added supports for modem signal, flow control
 * V1.3 - added long packet for tty_write
 * V1.4 - added ioctl for rs485 mode
 * V1.5 - fixed baud rate 0 bugs
 * V1.6 - fixed modem out bugs, added gpio function,
 *		- removed rs485 control(hardware auto supports)
 *		- added supports for baudrates 250k, 500k, 1M, 1.5M, 3M, 12M
 * V1.7 - added supports for break function
 * V1.8 - added supports for ch348
 * V1.9 - fixed os suspend/hibernate issues
 */

#define DEBUG
#define VERBOSE_DEBUG

#undef DEBUG
#undef VERBOSE_DEBUG

#include <linux/kernel.h>
#include <linux/errno.h>
#include <linux/init.h>
#include <linux/slab.h>
#include <linux/tty.h>
#include <linux/serial.h>
#include <linux/tty_driver.h>
#include <linux/tty_flip.h>
#include <linux/module.h>
#include <linux/mutex.h>
#include <linux/uaccess.h>
#include <linux/usb.h>
#include <asm/byteorder.h>
#include <asm/unaligned.h>
#include <linux/idr.h>
#include <linux/list.h>
#include <linux/version.h>
#include <linux/random.h>

#if (LINUX_VERSION_CODE >= KERNEL_VERSION(4, 11, 0))
#include <linux/sched/signal.h>
#endif

#include "ch9344.h"

#define DRIVER_AUTHOR "WCH@TECH39"
#define DRIVER_DESC "USB serial driver for ch9344/ch348."
#define VERSION_DESC "V1.9 On 2022.06"

#define IOCTL_MAGIC 'W'
#define IOCTL_CMD_GPIOENABLE	_IOW(IOCTL_MAGIC, 0x80, u16)
#define IOCTL_CMD_GPIODIR		_IOW(IOCTL_MAGIC, 0x81, u16)
#define IOCTL_CMD_GPIOSET		_IOW(IOCTL_MAGIC, 0x82, u16)
#define IOCTL_CMD_GPIOGET		_IOWR(IOCTL_MAGIC, 0x83, u16)
#define IOCTL_CMD_GETCHIPTYPE   _IOR(IOCTL_MAGIC, 0x84, u16)
#define IOCTL_CMD_CTRLIN 		_IOWR(IOCTL_MAGIC, 0x90, u16)
#define IOCTL_CMD_CTRLOUT		_IOW(IOCTL_MAGIC, 0x91, u16)

static struct usb_driver ch9344_driver;
static struct tty_driver *ch9344_tty_driver;

static DEFINE_IDR(ch9344_minors);
static DEFINE_MUTEX(ch9344_minors_lock);


static void ch9344_tty_set_termios(struct tty_struct *tty,
		struct ktermios *termios_old);

static int ch9344_get_portnum(int index);

static int ch9344_set_uartmode(struct ch9344 *ch9344, int portnum, u8 index, u8 mode);

/*
 * Look up an CH9344 structure by minor. If found and not disconnected, increment
 * its refcount and return it with its mutex held.
 */
static struct ch9344 *ch9344_get_by_index(unsigned int index)
{
	struct ch9344 *ch9344;

	mutex_lock(&ch9344_minors_lock);
	ch9344 = idr_find(&ch9344_minors, index / NUMSTEP);
	if (ch9344) {
		mutex_lock(&ch9344->mutex);
		if (ch9344->disconnected) {
			mutex_unlock(&ch9344->mutex);
			ch9344 = NULL;
		} else {
			tty_port_get(&ch9344->ttyport[ch9344_get_portnum(index)].port);
			mutex_unlock(&ch9344->mutex);
		}
	}
	mutex_unlock(&ch9344_minors_lock);

	return ch9344;
}

/*
 * Try to find an available minor number and if found, associate it with 'ch9344'.
 */
static int ch9344_alloc_minor(struct ch9344 *ch9344)
{
	int minor;

	mutex_lock(&ch9344_minors_lock);
	minor = idr_alloc(&ch9344_minors, ch9344, 0, CH9344_TTY_MINORS, GFP_KERNEL);
	mutex_unlock(&ch9344_minors_lock);

	return minor;
}

/* Release the minor number associated with 'ch9344'. */
static void ch9344_release_minor(struct ch9344 *ch9344)
{
	mutex_lock(&ch9344_minors_lock);
	idr_remove(&ch9344_minors, ch9344->minor);
	mutex_unlock(&ch9344_minors_lock);
}

static int ch9344_get_portnum(int index)
{
	return index % NUMSTEP;
}

/*
 * Functions for control messages.
 */
static int ch9344_control_out(struct ch9344 *ch9344, u8 request,
		u16 value, u16 index)
{
	int retval;

	retval = usb_autopm_get_interface(ch9344->data);
	if (retval)
		return retval;

	retval = usb_control_msg(ch9344->dev, usb_sndctrlpipe(ch9344->dev, 0),
			request, USB_TYPE_VENDOR | USB_RECIP_DEVICE | USB_DIR_OUT,
			value, index, NULL, 0, DEFAULT_TIMEOUT);

	usb_autopm_put_interface(ch9344->data);

	return retval < 0 ? retval : 0;
}

static int ch9344_control_in(struct ch9344 *ch9344,
		u8 request, u16 value, u16 index,
		char *buf, unsigned bufsize)
{
	int retval;

	retval = usb_autopm_get_interface(ch9344->data);
	if (retval)
		return retval;

	retval = usb_control_msg(ch9344->dev, usb_rcvctrlpipe(ch9344->dev, 0), request,
			USB_TYPE_VENDOR | USB_RECIP_DEVICE | USB_DIR_IN,
			value, index, buf, bufsize, DEFAULT_TIMEOUT);

	usb_autopm_put_interface(ch9344->data);

	return retval;
}

/*
 * Functions for CH9344 cmd messages.
 */
static int ch9344_cmd_out(struct ch9344 *ch9344, u8 *buf,
		int count)
{
	int retval, actual_len;

	retval = usb_bulk_msg(ch9344->dev, ch9344->cmdtx_endpoint,
			buf,
			min((unsigned int)count, ch9344->cmdsize),
			&actual_len, DEFAULT_TIMEOUT);

	if (retval) {
		dev_err(&ch9344->data->dev,
				"usb_bulk_msg(send) failed, err %i\n", retval);
		return retval;
	}

	if (actual_len != count) {
		dev_err(&ch9344->data->dev, "only wrote %d of %d bytes\n",
				actual_len, count);
		return -1;
	}

	return actual_len;
}

static inline int ch9344_set_control(struct ch9344 *ch9344,
		int portnum, int control)
{
	char *buffer;
	int retval;
	const unsigned size = 3;
	u8 rgadd = 0;

	if (ch9344->chiptype == CHIP_CH9344)
		rgadd = 0x10 * portnum + 0x08;
	else if (ch9344->chiptype == CHIP_CH348L) {
		if (portnum < 4)
			rgadd = 0x10 * portnum;
		else
			rgadd = 0x10 * (portnum - 4) + 0x08;
	}

	buffer = kzalloc(size, GFP_KERNEL);
	if (!buffer)
		return -ENOMEM;

	if (ch9344->quirks & QUIRK_CONTROL_LINE_STATE)
		return -EOPNOTSUPP;

	buffer[0] = CMD_W_BR;
	buffer[1] = rgadd + R_C4;
	buffer[2] = control;

	retval = ch9344_cmd_out(ch9344, buffer, size);

	kfree(buffer);

	return retval < 0 ? retval : 0;
}

static int ch9344_configure(struct ch9344 *ch9344, int portnum)
{
	char *buffer;
	int ret;
	u8 request;
	u8 rgadd = 0;

	buffer = kzalloc(ch9344->cmdsize, GFP_KERNEL);
	if (!buffer)
		return -ENOMEM;

	request = CMD_W_R;
	if (ch9344->chiptype == CHIP_CH9344)
		rgadd = 0x10 * portnum + 0x08;
	else if (ch9344->chiptype == CHIP_CH348L) {
		if (portnum < 4)
			rgadd = 0x10 * portnum;
		else
			rgadd = 0x10 * (portnum - 4) + 0x08;
	}

	buffer[0] = request;
	buffer[1] = rgadd + R_C2;
	buffer[2] = 0x87;
	ret = ch9344_cmd_out(ch9344, buffer, 0x03);
	if (ret < 0)
		goto out;

	if (ch9344->chiptype == CHIP_CH9344) {
		buffer[1] = rgadd + R_C3;
		buffer[2] = 0x03;
		ret = ch9344_cmd_out(ch9344, buffer, 0x03);
		if (ret < 0)
			goto out;
	}

	buffer[1] = rgadd + R_C4;
	buffer[2] = 0x08;
	ret = ch9344_cmd_out(ch9344, buffer, 0x03);
	if (ret < 0)
		goto out;
out:
	kfree(buffer);
	return ret < 0 ? ret : 0;
}
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

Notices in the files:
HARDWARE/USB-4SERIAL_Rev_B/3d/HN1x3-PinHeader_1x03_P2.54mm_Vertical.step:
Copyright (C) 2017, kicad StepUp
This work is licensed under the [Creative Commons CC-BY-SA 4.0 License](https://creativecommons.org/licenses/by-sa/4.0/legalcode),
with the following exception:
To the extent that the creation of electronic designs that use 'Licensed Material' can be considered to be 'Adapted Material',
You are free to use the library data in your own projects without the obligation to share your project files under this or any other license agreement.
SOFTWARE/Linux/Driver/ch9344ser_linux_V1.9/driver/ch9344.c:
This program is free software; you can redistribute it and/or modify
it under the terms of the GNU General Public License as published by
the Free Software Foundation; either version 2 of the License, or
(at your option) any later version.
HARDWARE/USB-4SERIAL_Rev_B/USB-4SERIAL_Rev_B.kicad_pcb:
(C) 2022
